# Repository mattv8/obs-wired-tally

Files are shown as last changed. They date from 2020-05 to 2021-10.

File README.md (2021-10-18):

THIS PROJECT IS DEPRECATED. PLEASE SEE THE FOLLOWING REPOSITORY FOR THE LATEST: https://github.com/mattv8/open-tally
==================================================

Project Overview
----------------------------
This project utilizes a Windows .NET app, OBS websocket plugin, Arduino Pro Micro, WS2812 RGB LEDs, and 3D printed hardware to build an inexpensive OBS Tally Light system that is power efficient and relatively easy to get up and running. The tally lights themselves are designed to work with a standard hot (or cold) shoe found on most DSLR's and camcorders.

(http://www.youtube.com/watch?v=zPsItWoxoUQ "")

Requirments to Build the Project
----------------------------
1. A computer with [OBS](https://obsproject.com/download) and the [OBS Websockets Plugin](https://obsproject.com/forum/resources/obs-websocket-remote-control-obs-studio-from-websockets.466/) installed.
2. Access to a 3D printer.
	- I recommend [Solutech White filament](https://www.amazon.com/gp/product/B01B5KFRHO/ref=ppx_yo_dt_b_search_asin_title?ie=UTF8&psc=1) for best LED color results. It's a translucent white filament that makes for a good light diffusion effect on the "bulb" part.
3. An [Arduino Pro Micro](https://www.amazon.com/OSOYOO-ATmega32U4-arduino-Leonardo-ATmega328/dp/B012FOV17O?th=1).
4. [WS2812B Ring Lamp](https://www.amazon.com/gp/product/B0105VMT4S/ref=ppx_yo_dt_b_search_asin_title?ie=UTF8&psc=1) or similar 23mm diameter.
5. [3.5 mm surface-mount headphone connector](https://www.amazon.com/dp/B0833WYLWQ/ref=dp_cerb_1).
6. [3.5 mm male-to-male headphone wire](https://www.amazon.com/gp/product/B004JWIPKM/ref=ppx_yo_dt_b_asin_title_o00_s01?ie=UTF8&psc=1). 
	- Recommended: purchase in 25 ft lengths or as necessary for the distance between your cameras.
7. Soldering iron and solder.
8. [28 AWG copper wire (recommended)](https://www.amazon.com/Electrical-different-Insulated-Temperature-Resistance/dp/B07G2HFCS1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).

Requirments to Contribute to the Project
----------------------------
I would welcome any software contributions! I have licensed the CAD parts and software as GPLv3. If you want to contribute to the software side, you will need the following:
1. Microsoft Visual Studio 2019
	- This project utilizes the [Costura.Fody](https://www.nuget.org/packages/Costura.Fody/) packager, which will have to be installed into MS Visual Studio with [NuGet](https://docs.microsoft.com/en-us/nuget/consume-packages/install-use-packages-visual-studio).
2. [Arduino IDE](https://www.arduino.cc/en/main/software).

If you want to contribute to the hardware side:
1. PTC Creo 5 for editing CAD files.
	- Unfortunately Creo is not free software. FOSS alternatives are [FreeCAD](https://www.freecadweb.org/), [OpenSCAD](https://www.openscad.org/) or [Blender](https://www.blender.org/download/).
	- I have provided STEP files in the "/CAD/STEP Files" folder that can be opened in other CAD programs.
	- I have provided STL files in the "/CAD/STL Files" that can be sent straight to your favorite slicer for 3D printing.

Credits
-----------------------------
- Project ideas from the following OBS forum thread: https://obsproject.com/forum/threads/live-cameara-led.73922/
- Arduino portion forked from https://boprograms.eu/obsTally/.

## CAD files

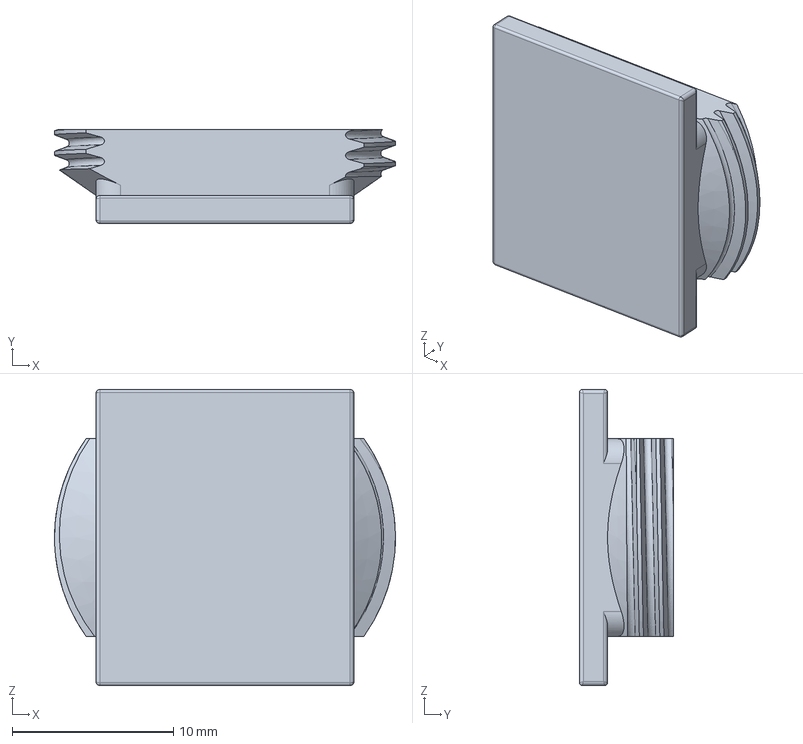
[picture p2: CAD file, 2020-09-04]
CAD/STEP Files/hotshoe_mount.stp
21.1 x 5.84 x 18.3 mm

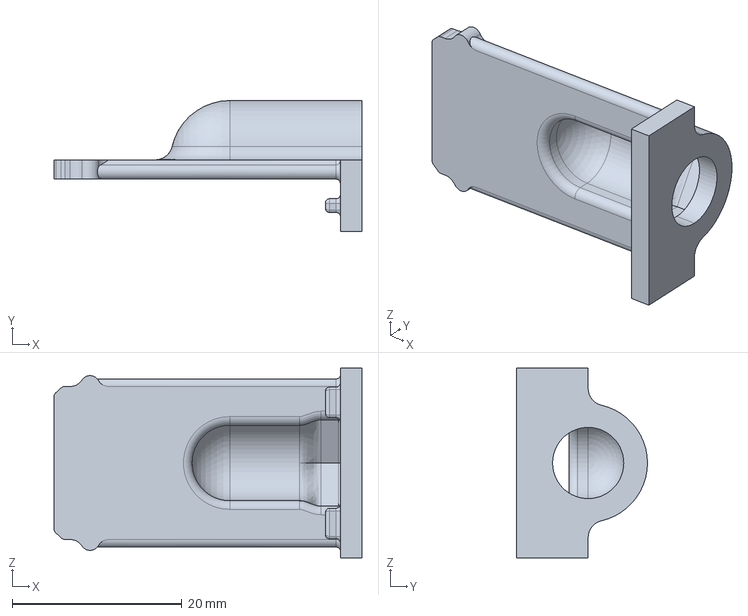
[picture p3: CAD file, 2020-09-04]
CAD/STEP Files/arduinoupperhousing.stp
36.3 x 15.4 x 22.4 mm

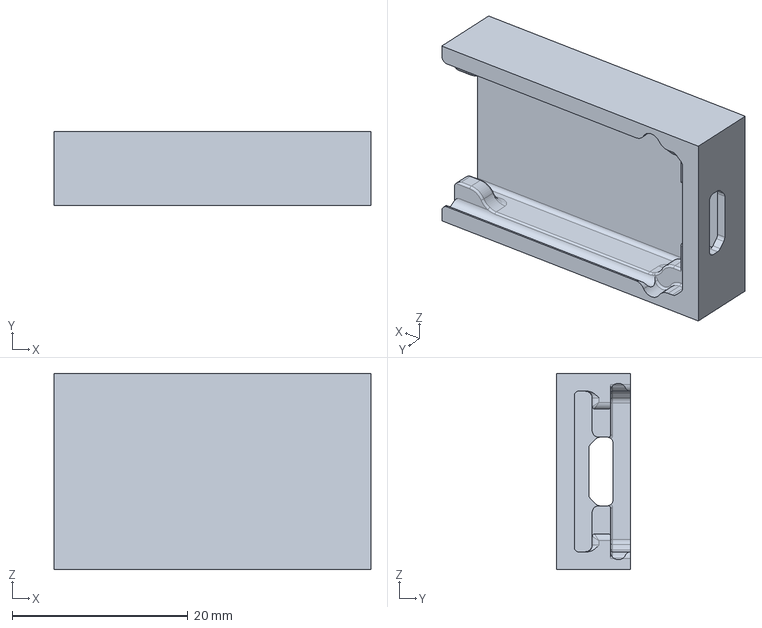
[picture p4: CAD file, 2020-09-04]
CAD/STEP Files/arduinolowerhousing.stp
36.1 x 8.44 x 22.4 mm

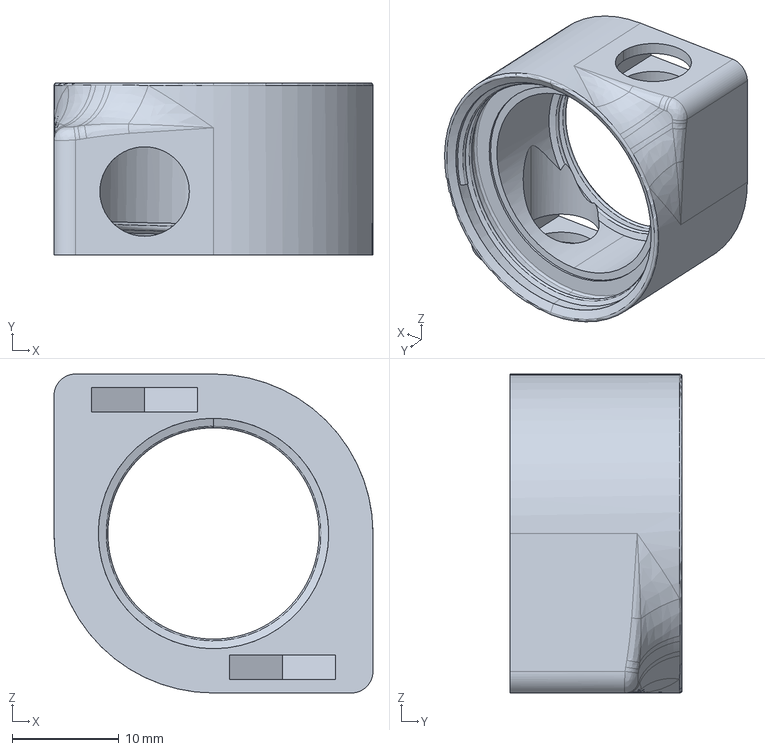
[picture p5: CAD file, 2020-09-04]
CAD/STEP Files/bulb_lower.stp
29.9 x 16.2 x 29.9 mm

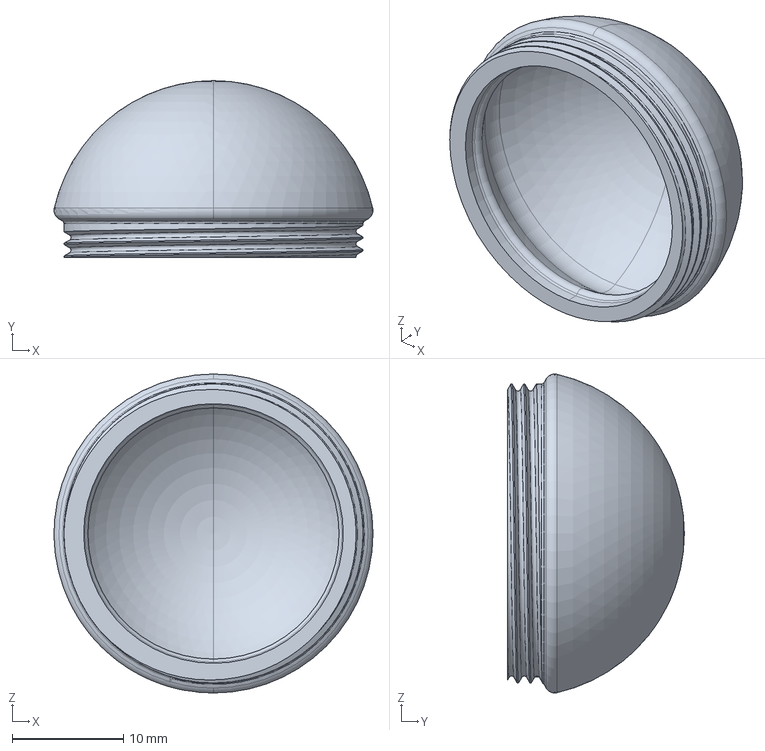
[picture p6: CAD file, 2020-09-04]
CAD/STEP Files/bulb.stp
28.7 x 15.9 x 28.7 mm

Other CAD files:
CAD/STL Files/arduinolowerhousing.stl
CAD/STL Files/arduinoupperhousing.stl
CAD/STL Files/bulb.stl
CAD/STL Files/bulb_lower.stl
CAD/STL Files/hotshoe_mount.stl

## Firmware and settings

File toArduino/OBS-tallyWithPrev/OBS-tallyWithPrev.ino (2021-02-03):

/////////////////////////////////////////////////////////////////////
//    SW-001 Software, Arduino Script for wired OBS Tally Light    //
/////////////////////////////////////////////////////////////////////
//
//  Written by: Matthew P. Visnovsky
//  Adapted from https://boprograms.eu/obsTally/.
//  Includes code by Mark Kriegsman.
//
#include "FastLED.h" //Using FastLED Library https://github.com/FastLED/FastLED

// Dependency check
#if FASTLED_VERSION < 3001000
#error "Requires FastLED 3.1 or later; check github for latest code."
#endif

// -----------------------PINS------------------------- //
#define Vout     2   // Digital
#define DATA_PIN A2  // PWM

// -----------------------GLOBAL VARIABLES------------------------- //

//Time variables
unsigned long currentTime;  //Initialize master clock as global variable.
unsigned long pastTime = 0; // Set pastTime to 0. Don't redefine this anywhere or it will break the blink function.

//FastLED Variables
#define LED_TYPE    WS2811
#define COLOR_ORDER GRB
#define DUTY_CYCLE  255                 //PWM duty cycle initialization
#define NUM_LEDS    7                   //Number of LEDs per tally lamp
#define NUM_SETS    4                   //Total number of tally lamps
#define TOTAL_LEDS  NUM_LEDS*NUM_SETS   //Total number of LEDs

//FastLED Data Structure Setup
CRGB rawleds[TOTAL_LEDS];
CRGBSet leds(rawleds, TOTAL_LEDS);    //Use this if you want to do things with all LEDs at once
CRGBSet set1(leds(NUM_LEDS*0,NUM_LEDS*1-1));
CRGBSet set2(leds(NUM_LEDS*1,NUM_LEDS*2-1));
CRGBSet set3(leds(NUM_LEDS*2,NUM_LEDS*3-1));
CRGBSet set4(leds(NUM_LEDS*3,NUM_LEDS*4-1));
struct CRGB * ledarray[] ={set1, set2, set3, set4}; 

// State Variables
int SerialState = 0; int lastSerialState = 0;
int currentPreview1; int currentPreview2; int currentPreview3; int currentPreview4;
int lastPreview1; int lastPreview2; int lastPreview3; int lastPreview4;
int currentLive1; int currentLive2; int currentLive3; int currentLive4;
int lastLive1; int lastLive2; int lastLive3; int lastLive4;

// Serial Variables
char readString[64];
int startbit;
int Idx1;
int Idx2;
int Idx3;
int Idx4;

// Misc Variables
int numLive = 1; int numPreview = 1;

// ------------------------FUNCTIONS------------------------ //

// This function reads the incoming serial stream and parses it into respective variables.
// We expect a string like  51,2,3,4*  or  50,2,*. For now, this only allows for up to 4
// sources, but we can manually modify the code to allow for more.
//   Serial Key:
//   50  = Preview state change
//   51  = Live state change
//   0-3 = Live/Preview source range
//   4   = Source is out of range
//   ,   = Delimiter
//   *   = Stop bit
void readSerial () {

  char *ptr;
  int charsRead;

  charsRead = Serial.readBytesUntil(',*', readString, sizeof(readString) - 1);
  readString[charsRead] = '\0';

  //Serial.print("Captured string is : "); Serial.println(readString);
  //Serial.print("Length of string is : "); Serial.println(strlen(readString));

  ptr = strtok(readString, ","); if (ptr != '\0') { startbit = atoi(ptr); }
  ptr = strtok('\0', ",");       if (ptr != '\0') { Idx1 = atoi(ptr); } else { Idx1 = -1; }
  ptr = strtok('\0', ",");       if (ptr != '\0') { Idx2 = atoi(ptr); } else { Idx2 = -1; }
  ptr = strtok('\0', ",");       if (ptr != '\0') { Idx3 = atoi(ptr); } else { Idx3 = -1; }
  ptr = strtok('\0', ",");       if (ptr != '\0') { Idx4 = atoi(ptr); } else { Idx4 = -1; }
  
  readString[0] = '\0'; //clears variable for new input
  
}

// This function draws rainbows with an ever-changing, widely-varying set of parameters. 
// Function credit goes to Mark Kriegsman (2015).
void rainbow() {
  static uint16_t sPseudotime = 0;
  static uint16_t sLastMillis = 0;
  static uint16_t sHue16 = 0;
 
  uint8_t sat8 = beatsin88( 87, 220, 250);
  uint8_t brightdepth = beatsin88( 341, 96, 224);
  uint16_t brightnessthetainc16 = beatsin88( 203, (25 * 256), (40 * 256));
  uint8_t msmultiplier = beatsin88(147, 23, 60);

  uint16_t hue16 = sHue16;//gHue * 256;
  uint16_t hueinc16 = beatsin88(113, 1, 3000);
  
  uint16_t ms = millis();
  uint16_t deltams = ms - sLastMillis ;
  sLastMillis  = ms;
  sPseudotime += deltams * msmultiplier;
  sHue16 += deltams * beatsin88( 400, 5,9);
  uint16_t brightnesstheta16 = sPseudotime;
  
  for( uint16_t i = 0 ; i < NUM_LEDS*NUM_SETS; i++) {
    hue16 += hueinc16;
    uint8_t hue8 = hue16 / 256;

    brightnesstheta16  += brightnessthetainc16;
    uint16_t b16 = sin16( brightnesstheta16  ) + 32768;

    uint16_t bri16 = (uint32_t)((uint32_t)b16 * (uint32_t)b16) / 65536;
    uint8_t bri8 = (uint32_t)(((uint32_t)bri16) * brightdepth) / 65536;
    bri8 += (255 - brightdepth);
    
    CRGB newcolor = CHSV( hue8, sat8, bri8);
    
    uint16_t pixelnumber = i;
    pixelnumber = (NUM_LEDS*NUM_SETS-1) - pixelnumber;
    
    nblend( leds[pixelnumber], newcolor, 64);
  }
}

// ------------------------SETUP LOOP------------------------------- //
void setup() {
 
  // Tell FastLED about the LED array configuration.
  FastLED.addLeds<LED_TYPE,DATA_PIN,COLOR_ORDER>(leds, TOTAL_LEDS)
    .setCorrection(TypicalSMD5050)
    .setDither(DUTY_CYCLE < 255);
  
  // Pin mode initializations //
  pinMode(Vout, OUTPUT);

  // Pin digital writes //
  digitalWrite(Vout,HIGH); // Give power to the LED

  delay(2000); //Safety delay

}//End Setup Loop

// ------------------------VOID LOOP------------------------------- //
void loop(void) {

  ////////////// Perpetually Updating ///////////////
  //currentTime = millis(); // Update the master clock

  // Clear out all the LEDs upon serial state change
  SerialState = Serial.available();
  if (SerialState != lastSerialState) {
    FastLED.clear();
  }
  
  ////////////// Serial Communication ///////////////
  if(Serial.available()) { // Check if recieving data

    readSerial(); // Record serial bits from incoming serial stream.

    ////////////// Preview Range //////////////
    if (startbit == 50) { currentPreview1 = Idx1; currentPreview2 = Idx2; currentPreview3 = Idx3; currentPreview4 = Idx4; }
    
    ////////////// Live Range //////////////
    if (startbit == 51) { currentLive1 = Idx1; currentLive2 = Idx2; currentLive3 = Idx3; currentLive4 = Idx4; }

    ////////////// Tally Light States ///////////////
    // Preview State //
    if(lastPreview1 >= 0 || lastPreview1 != currentPreview1){ fill_solid( ledarray[lastPreview1], NUM_LEDS, CRGB::Black ); lastPreview1 = currentPreview1; }
    if(lastPreview2 >= 0 || lastPreview2 != currentPreview2){ fill_solid( ledarray[lastPreview2], NUM_LEDS, CRGB::Black ); lastPreview2 = currentPreview2; }
    if(lastPreview3 >= 0 || lastPreview3 != currentPreview3){ fill_solid( ledarray[lastPreview3], NUM_LEDS, CRGB::Black ); lastPreview3 = currentPreview3; }
    if(lastPreview4 >= 0 || lastPreview4 != currentPreview4){ fill_solid( ledarray[lastPreview4], NUM_LEDS, CRGB::Black ); lastPreview4 = currentPreview4; }
    
    // Live State //
    if(lastLive1 >= 0 || lastLive1 != currentLive1){ fill_solid( ledarray[lastLive1], NUM_LEDS, CRGB::Black ); lastLive1 = currentLive1; }
    if(lastLive2 >= 0 || lastLive2 != currentLive2){ fill_solid( ledarray[lastLive2], NUM_LEDS, CRGB::Black ); lastLive2 = currentLive2; }
    if(lastLive3 >= 0 || lastLive3 != currentLive3){ fill_solid( ledarray[lastLive3], NUM_LEDS, CRGB::Black ); lastLive3 = currentLive3; }
    if(lastLive4 >= 0 || lastLive4 != currentLive4){ fill_solid( ledarray[lastLive4], NUM_LEDS, CRGB::Black ); lastLive4 = currentLive4; }

    // Continually update current previews
    if(currentPreview1 >= 0){ fill_solid( ledarray[currentPreview1], NUM_LEDS, CRGB::Green ); numPreview = numPreview + 1; }
    if(currentPreview2 >= 0){ fill_solid( ledarray[currentPreview2], NUM_LEDS, CRGB::Green ); numPreview = numPreview + 1; }
    if(currentPreview3 >= 0){ fill_solid( ledarray[currentPreview3], NUM_LEDS, CRGB::Green ); numPreview = numPreview + 1; }
    if(currentPreview4 >= 0){ fill_solid( ledarray[currentPreview4], NUM_LEDS, CRGB::Green ); numPreview = numPreview + 1; }

    // Continually update current lives
    if(currentLive1 >= 0){ fill_solid( ledarray[currentLive1], NUM_LEDS, CRGB::Red ); numLive = numLive + 1; }
    if(currentLive2 >= 0){ fill_solid( ledarray[currentLive2], NUM_LEDS, CRGB::Red ); numLive = numLive + 1; }
    if(currentLive3 >= 0){ fill_solid( ledarray[currentLive3], NUM_LEDS, CRGB::Red ); numLive = numLive + 1; }
    if(currentLive4 >= 0){ fill_solid( ledarray[currentLive4], NUM_LEDS, CRGB::Red ); numLive = numLive + 1; }
        
    // Set duty cycle based on count of live and preview tallies
    if ( numPreview > 0 && numPreview <= 1 || numLive > 0 && numLive <= 1 ) { FastLED.setBrightness(DUTY_CYCLE*.50); }// Only 1 light, use 50% duty cycle
    if ( numPreview > 1 && numPreview <= 2 || numLive > 1 && numLive <= 2 ) { FastLED.setBrightness(DUTY_CYCLE*.10); }// Only 2 lights, use 10% duty cycle
    if ( numPreview > 2 || numLive > 2 ) { FastLED.setBrightness(DUTY_CYCLE*.05); }// 2 or more lights, use 5% duty cycle
    numLive = 0; numPreview = 0; // Reset live/preview counters

  }else { //If not recieving any data
    
    FastLED.setBrightness(DUTY_CYCLE*.05);//5% duty cycle for all lights at once
    rainbow(); //Fill all LEDs with beautiful dancing rainbows while we wait for Serial
    
  }//End Serial.available()

  FastLED.show(); //Send LED color states to the LEDs
  lastSerialState = SerialState; //Update serial state
  
}//End Void Loop

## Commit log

2020-05-17 Release of major Arduino script changes
2020-06-08 Initial release of CAD
    Releasing CAD models for enclosure for OBS Tally (non Wi-Fi model)
2020-06-22 CAD release 2.0
    CAD updates
    [bulb.prt]
2020-06-22 Filename fix
    [bulb.prt]
2020-07-02 Duty cycle and serial state
    -Updated the duty cycle to avoid flicker due to voltage drop.
    -Added serial state edge detection so LEDs will clear out when serial begins.
    [OBS-tallyWithPrev.ino]
2020-08-24 CAD File restructuring
2020-09-04 Added STEP files
    Added STEP files for open-source CAD
    [arduinolowerhousing.stp, arduinoupperhousing.stp, bulb.stp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]
2020-09-04 Added STL files
    Added STL files for 3D printing
    [arduinolowerhousing.stl, arduinoupperhousing.stl, bulb.stl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]
2020-11-09 Read from Arduino Serial
    Added functionality to read from Arduino serial
2020-11-13 Release 3.1
    Tallies by Source are now working on Arduino as well as the .NET app. I had to massively rewrite Arduino code to account for multiple tallies online at once.
2020-11-15 Release 3.2
    UI tweaks, bugfixes and error handling.
    [OBS-tallyWithPrev.ino]
